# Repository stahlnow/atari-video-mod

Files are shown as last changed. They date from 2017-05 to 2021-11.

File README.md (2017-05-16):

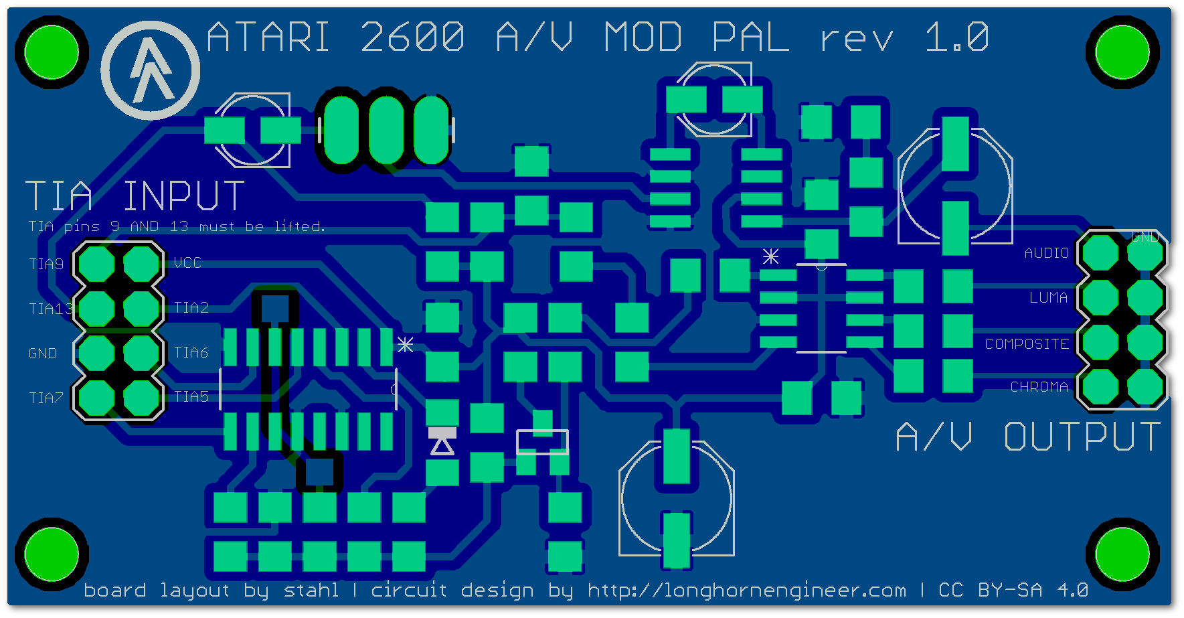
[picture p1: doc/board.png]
board gerber screenshot


# BOM

| Part | Value | Device | Package | Description |
|---|---|---|---|---|
| C1, C7, C8, C9 | 100nF | CAP1206 | 1206 | Capacitor |
| C2 | 100uF | CPOL-USD | PANASONIC_D | POLARIZED CAPACITOR, American symbol |
| C3, C4 | 10uF | CPOL-USB | PANASONIC_B | POLARIZED CAPACITOR, American symbol |
| C5 | 50nF | CAP1206 | 1206 | Capacitor |
| C6 | 250uF | CPOL-USD | PANASONIC_D | POLARIZED CAPACITOR, American symbol |
| C10 | 10uF | CAP1206 | 1206 | Capacitor |
| D1 | 1N914 | DIODE-SOD80C | SOD80C | DIODE |
| IC1 | LM386 | LM386M-1 | SO08 | Low Voltage Audio Power Amplifier |
| JP1 | | M03LONGPADS | 1X03_LONGPADS | Header 3 |
| Q1 | 2N3904 | TRANSISTOR_NPNSOT23 | SOT23 | Generic NPN BJT |
| R1 | 1.8K | RESISTOR1206 | 1206 | Resistor |
| R2, R9 | 10 | RESISTOR1206 | 1206 | Resistor |
| R3 | 1.5K | RESISTOR1206 | 1206 | Resistor |
| R4 | 18K | RESISTOR1206 | 1206 | Resistor |
| R5 | 9.1K | RESISTOR1206 | 1206 | Resistor |
| R6 | 36K | RESISTOR1206 | 1206 | Resistor |
| R7 | 1.6K | RESISTOR1206 | 1206 | Resistor |
| R8 | 2K | RESISTOR1206 | 1206 | Resistor |
| R10, R12, R13, R14, R15, R16, R17 | 75 | RESISTOR1206 | 1206 | Resistor |
| R11 | 1K | RESISTOR1206 | 1206 | Resistor |
| U1 | CD74HC4050M | CD74HC4050M | SOIC127P600X175-16N | High-Speed CMOS Logic Hex Buffers, Inverting and Non-Inverting |
| U2 | FMS6400 | FMS6400 | SOIC-8 | The FMS6400-1 is a dual Y/C 5 -order Butterworth low- |
| X1, X2 | M04X2 | M04X2 | 2X4 | .1" header, two rows of four. |
| LOGO1 | OSHW-LOGOS  | OSHW-LOGOS | OSHW-LOGO-S | Open Source Hardware Logo This logo indicates the piece of hardware it is found on incorporates a OSHW license and/or adheres to the definition of open source hardware found here: http://freedomdefined.org/OSHW |

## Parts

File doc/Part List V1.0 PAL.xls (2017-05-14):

Part | Mouser Part Number | Quantity
100uF Cap | 140-L16V100-RC | 1
.1uF Cap | 581-5ZH104ZEDAA | 2
10uF Cap | 810-FK20X7R1C106M | 1
1uF Cap | 140-L50V1.0-RC | 2
1N914 | 512-1N914BTR | 1
2N3904 | 512-2N3904BU | 1
1.5K | 660-CFS1/4CT52R152J | 1
10 | 660-CFS1/4CT52R100J | 1
9.1K | 660-CFS1/4CT52R912J | 1
36K | 660-CFS1/4CT52R363J | 1
18K | 660-CFS1/4CT52R183J | 1
75 | 660-CFS1/4CT52R750J | 10
2K | 660-CFS1/4CT52R202J | 1
1.6K | 660-CFS1/4CT52R162J | 1
1K | 660-CFS1/4C102J | 1
1.8K | 660-CFS1/4CT52R182J | 2
CD74HC4050E | 595-CD74HC4050E | 1
FMS6400 | 512-FMS6400CSX | 1
S-Video Jack | 161-2104 | 1
RCA Jack Y | 502-BPJF04X | 1 | 502-BPJF04AUX
RCA Jack W | 502-BPJF03X | 1 | 502-BPJF03AUX
RCA Jack R | 502-BPJF02X | 1 | 502-BPJF02AUX
Wire | 523-111-2213-010FT | 1

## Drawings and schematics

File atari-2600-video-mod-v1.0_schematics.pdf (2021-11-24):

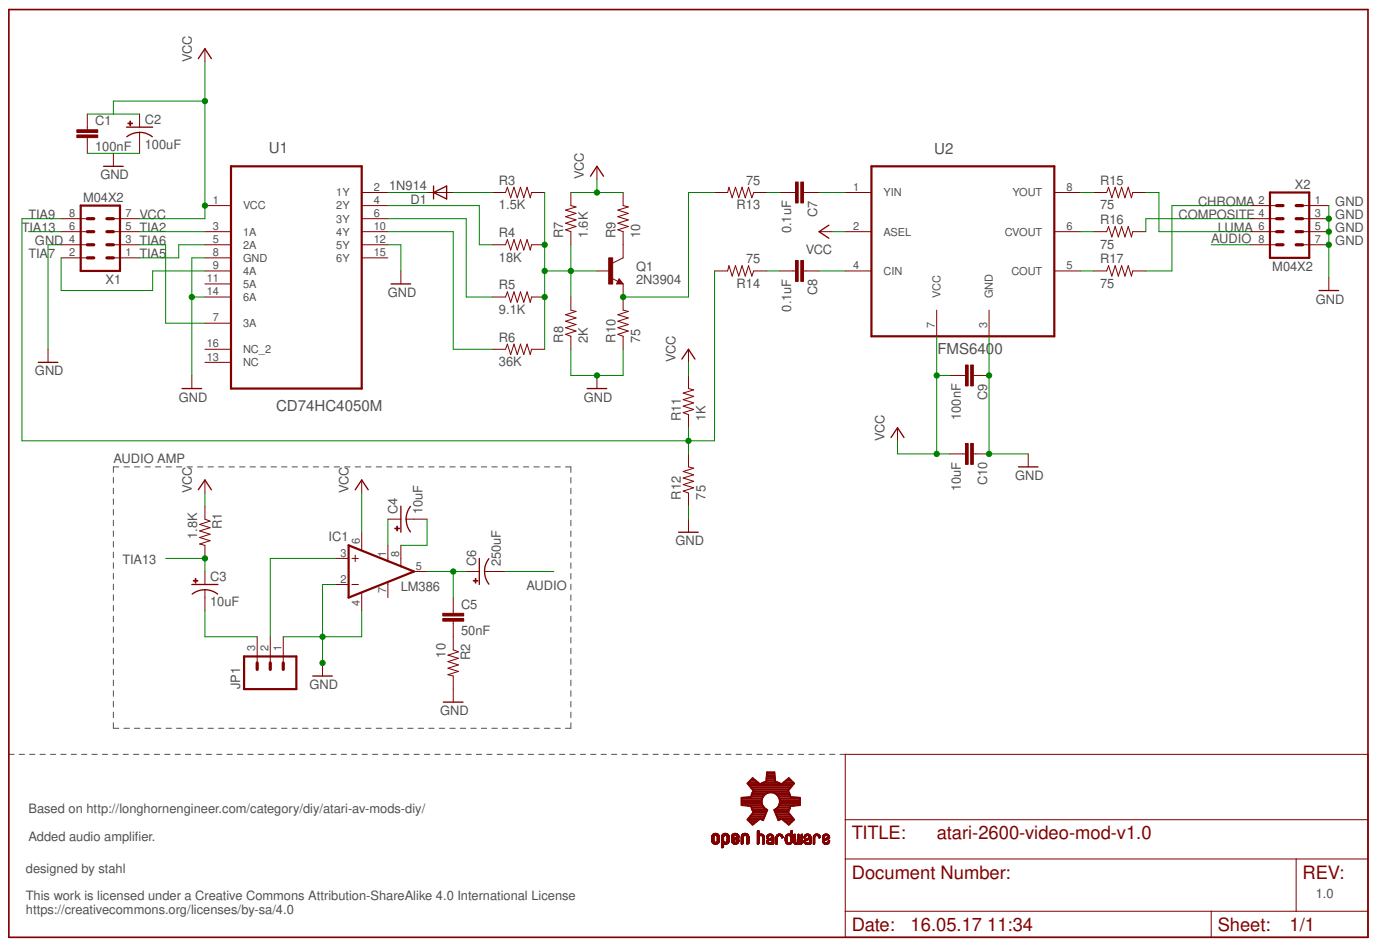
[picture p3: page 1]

6 4 | 5 TIA2 | 10
3 TIA6 | 12

Based on http://longhornengineer.com/category/diy/atari-av-mods-diy/

Document Number: | REV:

This work is licensed under a Creative Commons Attribution-ShareAlike 4.0 International License
https://creativecommons.org/licenses/by-sa/4.0

Date: 16.05.17 11:34 | Sheet: 1/1

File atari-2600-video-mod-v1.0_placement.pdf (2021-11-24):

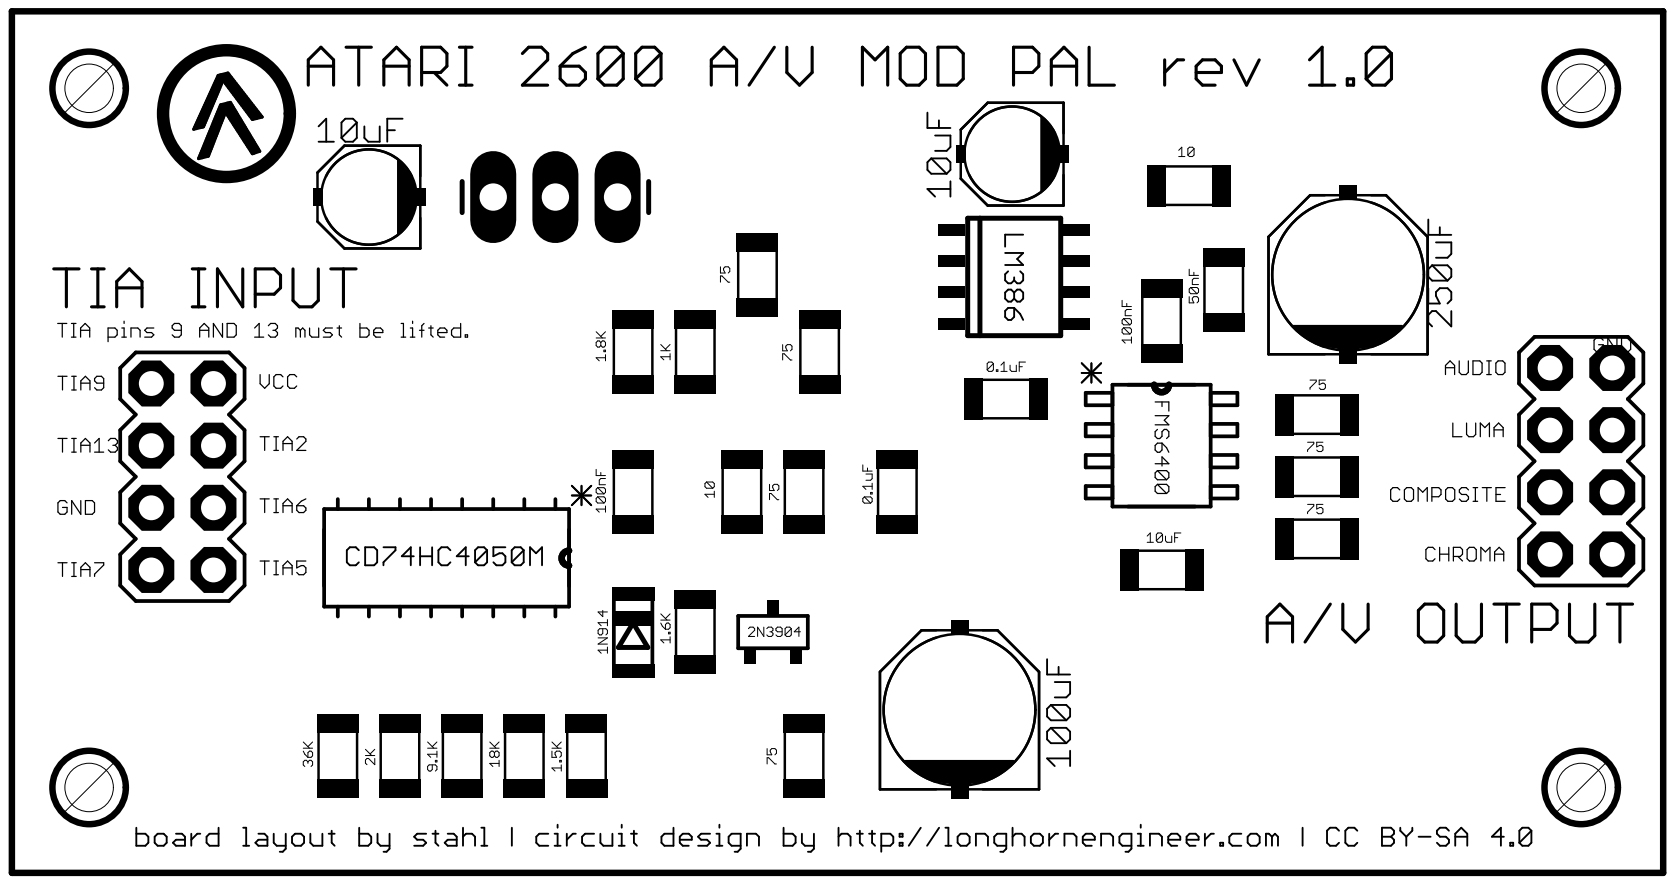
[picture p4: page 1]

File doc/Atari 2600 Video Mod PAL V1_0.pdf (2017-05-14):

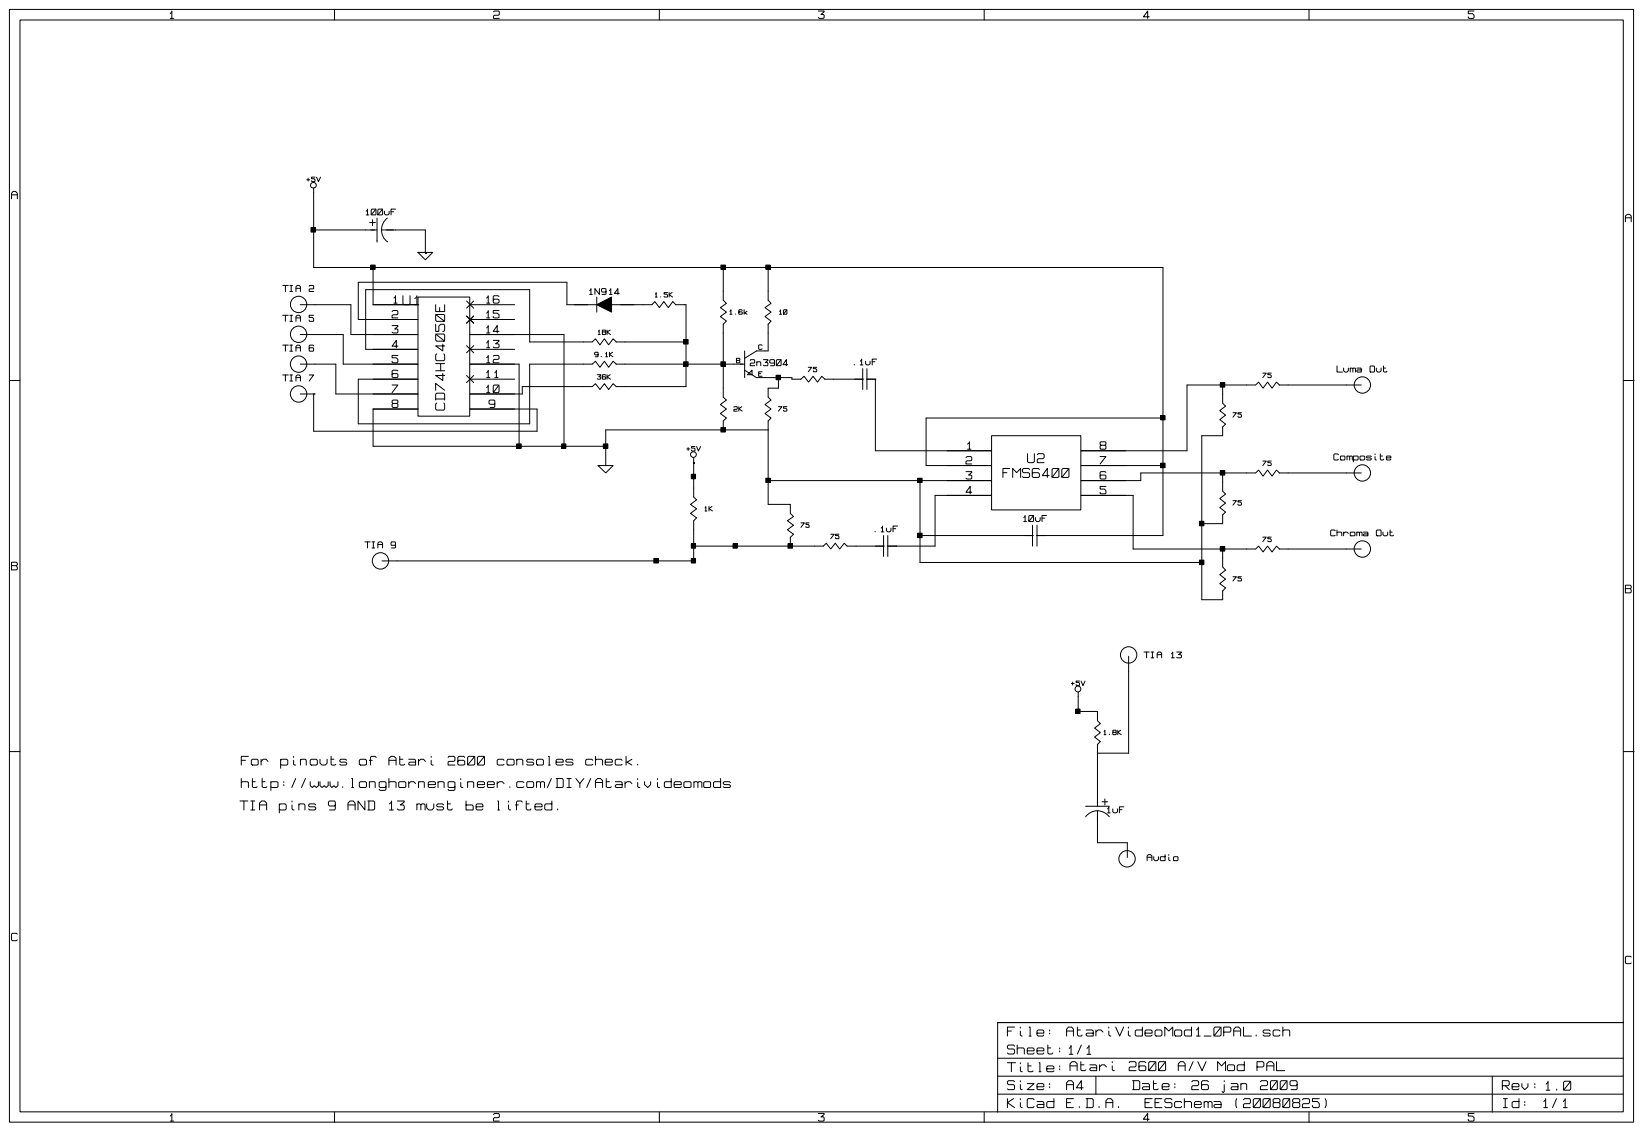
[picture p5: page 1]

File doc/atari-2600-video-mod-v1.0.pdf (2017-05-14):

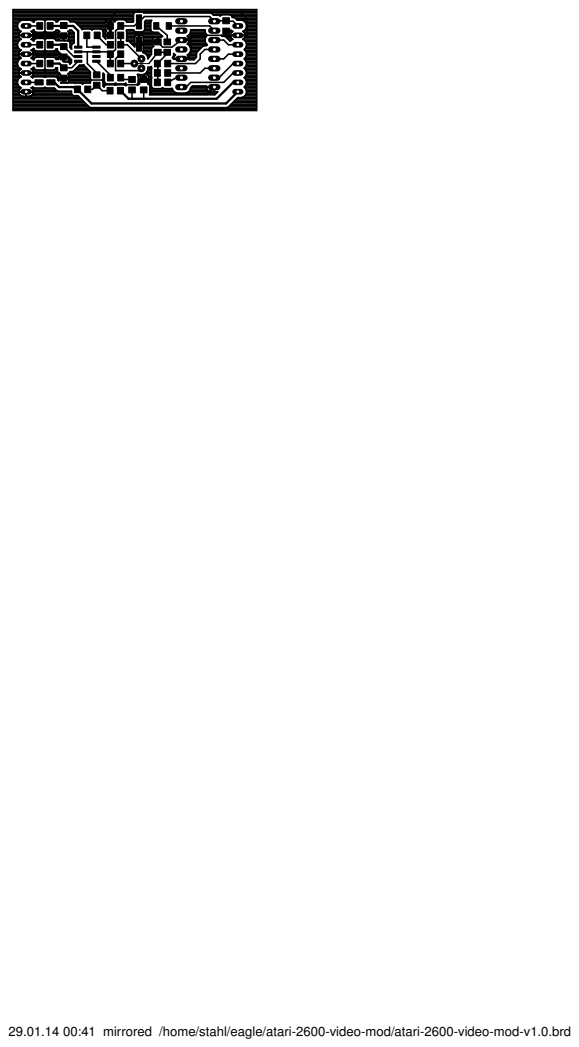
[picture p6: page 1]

29.01.14 00:41 mirrored /home/stahl/eagle/atari-2600-video-mod/atari-2600-video-mod-v1.0.brd

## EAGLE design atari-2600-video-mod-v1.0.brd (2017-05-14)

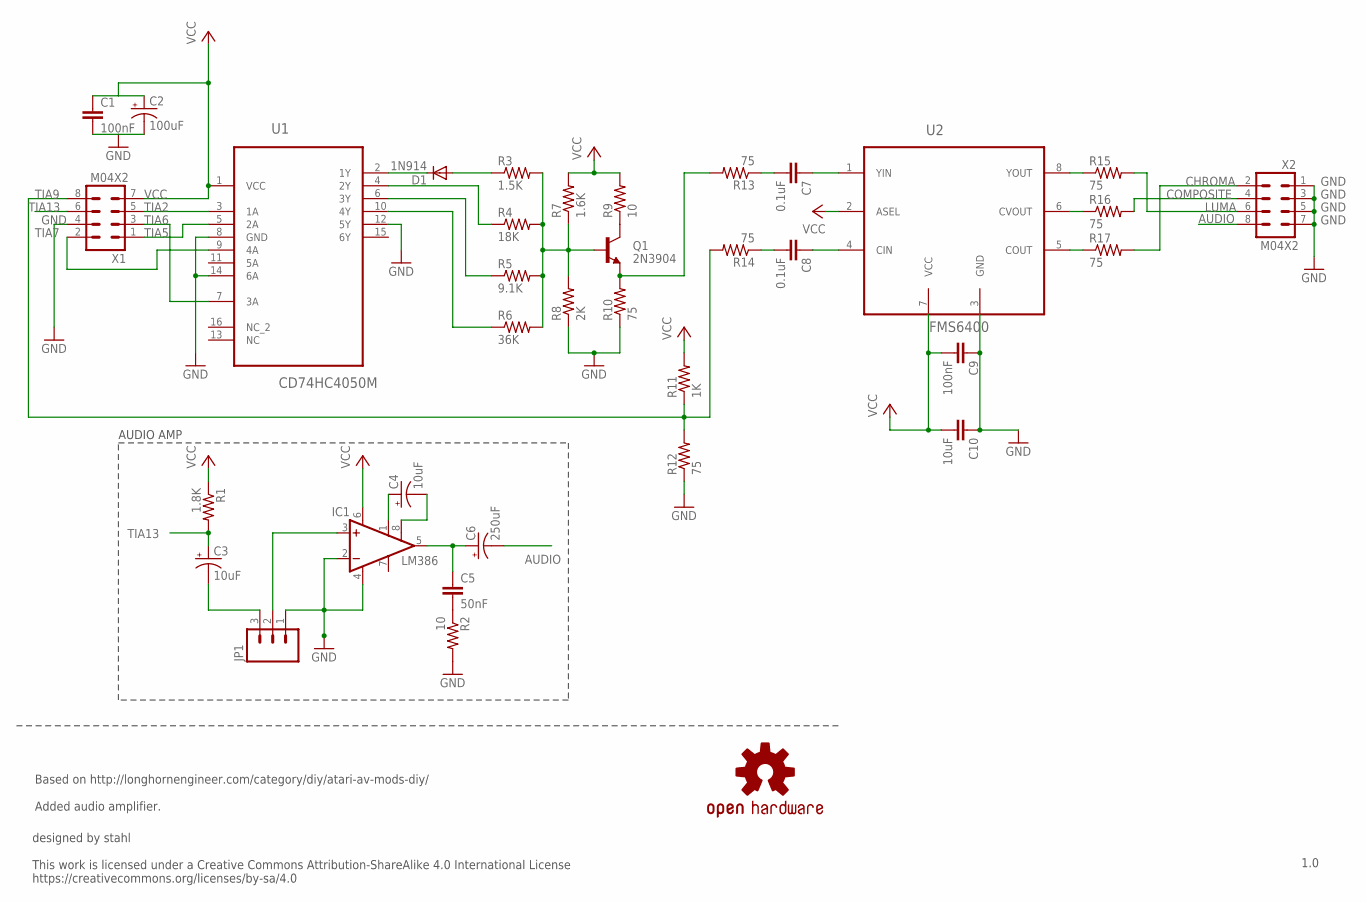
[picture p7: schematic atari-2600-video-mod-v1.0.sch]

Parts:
C1, C9: 100nF; 1206
C2: 100uF; PANASONIC_D
C3, C4: 10uF; PANASONIC_B
C5: 50nF; 1206
C6: 250uF; PANASONIC_D
C7, C8: 0.1uF; 1206
C10: 10uF; 1206
D1: 1N914; SOD80C
IC1: LM386; SO08
JP1: M03LONGPADS; 1X03_LONGPADS
LOGO1: OSHW-LOGOS; OSHW-LOGO-S
Q1: 2N3904; SOT23
R1: 1.8K; 1206
R2, R9: 10; 1206
R3: 1.5K; 1206
R4: 18K; 1206
R5: 9.1K; 1206
R6: 36K; 1206
R7: 1.6K; 1206
R8: 2K; 1206
R10, R12, R13, R14, R15, R16, R17: 75; 1206
R11: 1K; 1206
U1: CD74HC4050M; SOIC127P600X175-16N
U2: FMS6400; SOIC-8
X1, X2: M04X2; 2X4

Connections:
AUDIO: C6.-, X2.8
CHROMA: R17.2, X2.2
COMPOSITE: R16.2, X2.4
GND: C1.2, C2.-, C9.1, C10.1, IC1.2 (-IN), IC1.4 (GND), JP1.1, R2.2, R8.1, R10.1, R12.1, U1.8 (GND), U1.12 (5Y), U1.14 (6A), U2.3 (GND), X1.4, X2.1, X2.3, X2.5, X2.7
LUMA: R15.2, X2.6
unnamed: C8.1, U2.4 (CIN)
unnamed: R4.1, U1.4 (2Y)
unnamed: R5.1, U1.6 (3Y)
unnamed: R6.1, U1.10 (4Y)
unnamed: IC1.3 (+IN), JP1.2
unnamed: D1.C, U1.2 (1Y)
unnamed: D1.A, R3.1
unnamed: Q1.3 (C), R9.1
unnamed: Q1.2 (E), R10.2, R13.2
unnamed: C7.1, U2.1 (YIN)
unnamed: C7.2, R13.1
unnamed: C8.2, R14.1
unnamed: R15.1, U2.8 (YOUT)
unnamed: R17.1, U2.5 (COUT)
unnamed: R16.1, U2.6 (CVOUT)
unnamed: C4.+, IC1.1 (GAIN)
unnamed: C4.-, IC1.8 (GAIN)
unnamed: Q1.1 (B), R3.2, R4.2, R5.2, R6.2, R7.1, R8.2
unnamed: C5.2, R2.1
unnamed: C5.1, C6.+, IC1.5 (OUT)
unnamed: C3.-, JP1.3
TIA2: U1.3 (1A), X1.5
TIA5: U1.5 (2A), X1.1
TIA6: U1.7 (3A), X1.3
TIA7: U1.9 (4A), X1.2
TIA9: R11.1, R12.2, R14.2, X1.8
TIA13: C3.+, R1.2, X1.6
VCC: C1.1, C2.+, C9.2, C10.2, IC1.6 (VS), R1.1, R7.2, R9.2, R11.2, U1.1 (VCC), U2.2 (ASEL), U2.7 (VCC), X1.7

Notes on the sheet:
AUDIO AMP
Based on http://longhornengineer.com/category/diy/atari-av-mods-diy/ Added audio amplifier.
1.0

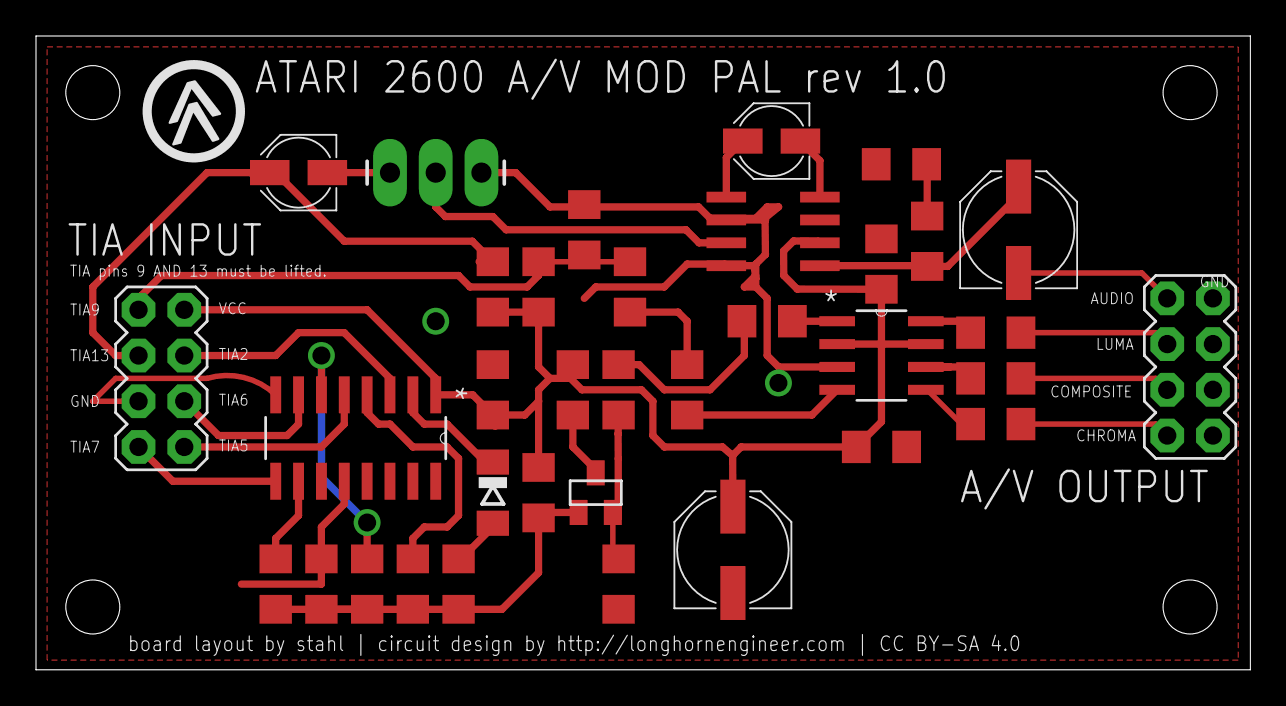
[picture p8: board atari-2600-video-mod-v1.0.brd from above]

Board: 2 copper layers, 67.5 x 35.2 mm, 37 parts (1 on the bottom side), 33 nets.

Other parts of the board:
U$1: ATARI-AGE

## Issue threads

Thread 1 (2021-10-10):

Component labels on the PCB not on silkscreen

repetto74, 2021-10-10:
Hi,
Thank you for this project which looks nice and would like to build the pcb for s-video on the Atari 2600.
There is no marking on the PCB for the components labels listed in the BOM. How I am supposed to know where each components goes? Although it is pretty obvious for the IC's it is more complicated for resistors and caps.
Kind regards,
Rick

stahlnow, 2021-11-24:
hello! thanks for your interest in building one! i added two pdf (schematics and placement) that will help you with the assembly. kind regards, stahl

Closed 2021-11-24.

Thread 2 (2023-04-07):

Audio Amplifier question

Metacrack, 2023-04-07:
Hello,
really interesting project!
I have one question about the routing of the amplifier.
Are pin 2 and 3 supposed to be shorted to get the signal amplified?
Thank you

stahlnow, 2023-04-16:
Hi!
No, they should not be shorted. You can see the connections in the schematics:
https://github.com/stahlnow/atari-video-mod/blob/master/atari-2600-video-mod-v1.0_schematics.pdf

I think I might still have PCBs. If you are interested, I can send you one.

Cheers!

Metacrack, 2023-04-16:
Thank you for your reply!
So, maybe it's a noob question but, looking at the schematic I understand that on Pin 1 of JP1 you have the audio signal coming from TIA13 and this signal should be amplified by the LM386. But the input signal of LM386 is only connected to Pin 2 of JP1...I supposed this signal should be routed to the input.
What's coming out from AUDIO?

Ciao, Gianluca

stahlnow, 2023-04-19:
Hi!

I get you confusion now... at JP1 a volume potentiometer should be connected. I missed designating this in the schematics.

So Audio is coming from TIA13 through the audio amp / volume potentiometer. M04X2 is the output, a pinheader that you can connect RCA jacks, ie. a yellow one for composite video signal and a red one for audio.

Hope this clears things up!

Cheers!

Metacrack, 2023-04-19:
Now I got it!
Thank you

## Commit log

2017-05-14 fixed logo :punch:
    [atari-2600-video-mod-v1.0.brd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]
2017-05-16 add bom :punch:

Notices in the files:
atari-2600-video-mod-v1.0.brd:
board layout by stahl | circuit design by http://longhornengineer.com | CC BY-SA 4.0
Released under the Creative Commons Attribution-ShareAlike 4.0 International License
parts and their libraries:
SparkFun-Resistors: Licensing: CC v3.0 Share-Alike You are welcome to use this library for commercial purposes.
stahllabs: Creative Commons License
